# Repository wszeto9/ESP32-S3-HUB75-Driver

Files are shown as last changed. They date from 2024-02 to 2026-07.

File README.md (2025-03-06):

# ESP32-S3-HUB75-Driver

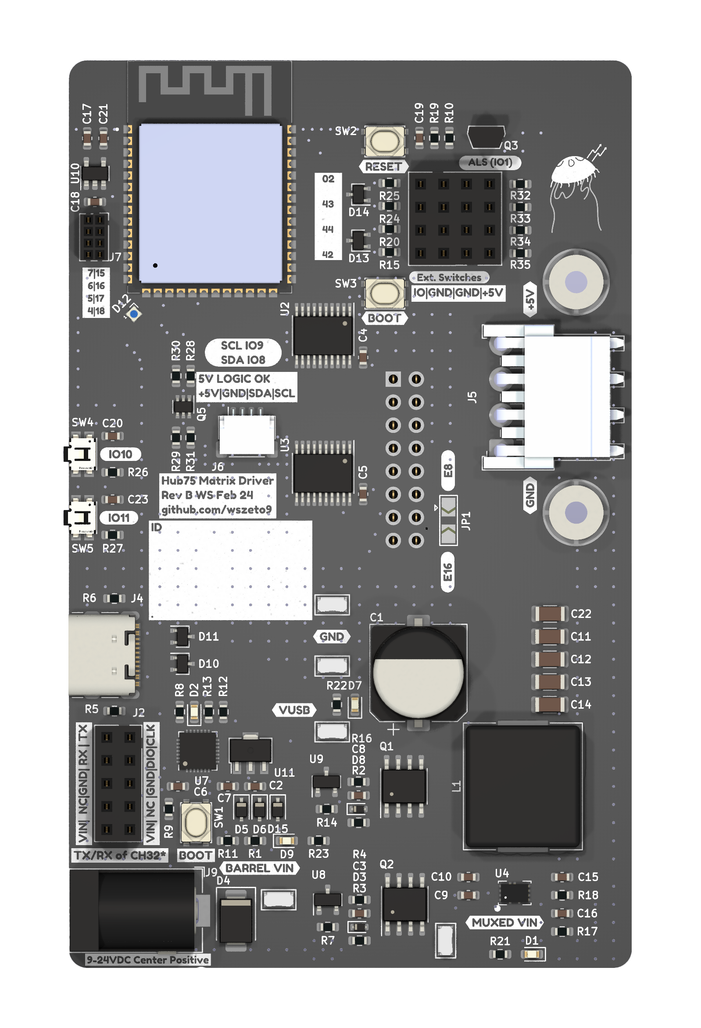
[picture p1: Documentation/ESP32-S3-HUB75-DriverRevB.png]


This board serves as the Matrix Display driver for MIT's 2.007 gameboards in Spring 2024 and Spring 2025. The board can take 4 button inputs, Stemma-QT I2C sensors, and breaks out 8 GPIO pins for future use. The board also features a ambient light sensor to adjust brightness in real time, as well as two buttons to switch modes if needed. The board supports USB-C PD power input up to 20V and USB debugging, as well as a 5.5mm OD / 2.1mm ID barrel jack for 9-24V input. A 5V/6A Buck converter helps ensure that the display is adequately powered. For this reason, it's recommended to power the display off a source higher than 5V for long term purposes. 

The board contains a power mux that automatically switches power sources based on what's present. It will always choose the first power source that's provided. If debugging is desired, it's recommended to first plug in the barrel jack for power, then use the USB port for debugging. This ensures lower power draw from the host computer. 

Upon power up, D7 or D9 will light up based on what power source is present. D2 should blink in accordance to the voltage of the power source (ie 5 blinks is a 5V source). D1 indicates that power is properly being delivered to the converter. 

At this point, the ESP32-S3 should pop up as a virtual COM port over USB. Boot and reset buttons are located by the ESP, but they may not be needed to perform DFU. 

Note: E8 and E16 refer to the pin that is used to act as pin E. This is only present on 64x64 pixel displays and larger. Some displays use pin 8, some displays use pin 16. Adafruit claims they use pin 8 for address E, so use a solder blob to jump the jumper to E8.

Further documentation can be found under the specific firmware builds.

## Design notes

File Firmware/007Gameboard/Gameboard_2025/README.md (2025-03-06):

# 2.007 Spring 2025 Gameboard - Lever Display
This firmware is for the lever displays on the 2.007 Spring 2025 gameboard. The initial codebase is copied from the 2024 Button Displays.

One of the major changes in this firmware compared to most other code one might encounter is that everything is implemented in timer and interrupt peripherals. This means that the flow of the code is quite different from what most people learn when they first start writing code. [Here's a link](https://users.ece.utexas.edu/~valvano/Volume1/E-Book/C12_Interrupts.htm) to learn about interrupts.

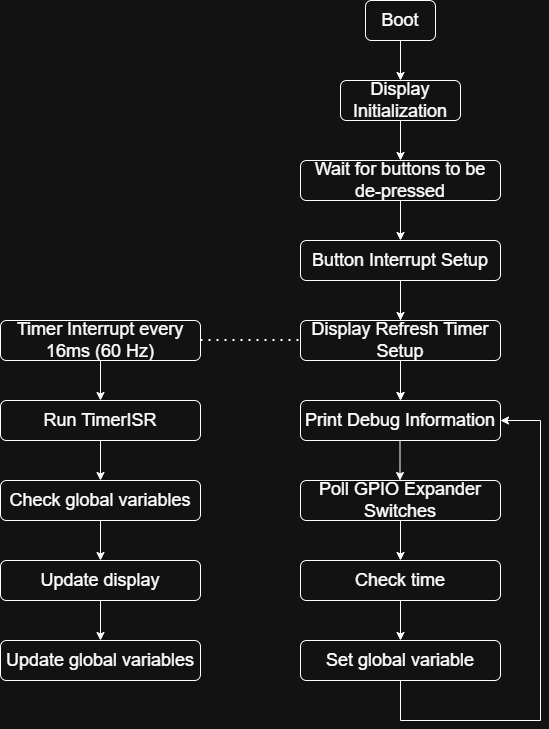
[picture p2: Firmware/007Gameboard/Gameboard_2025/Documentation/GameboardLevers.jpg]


Suggested flowchart for the firmware

The central flow diagram is what is typically taught in code structure. Here, initialization and setup code (usually in `void setup(){}`) is run once and code that repeats is run in a loop (usually in `void loop(){}`). What is special is the two other flow structures on the left and right. They get initialized in setup. 

Timers can trigger interrupts! Timer setups are a lot more hardware-dependent, so refer to the [ESP32 Arduino Framework documentation](https://espressif-docs.readthedocs-hosted.com/projects/arduino-esp32/en/latest/api/timer.html) on how to set up a timer. The timer in this case is set up to interrupt every 16ms, which equiates to about 60 Hz. Once the timer expires, `timerISR` is called, which updates the display. For more specific documentation on all the functions used to draw images to displays, see the dependent [ESP32-HUB75-MatrixPanel-DMA library](https://github.com/mrcodetastic/ESP32-HUB75-MatrixPanel-DMA).

For bitmaps, the `drawXBM565` function is called. This pulls a bitmap array from memory to draw it on the display. There's more documentation on this [here in the examples](https://github.com/mrcodetastic/ESP32-HUB75-MatrixPanel-DMA/tree/master/examples/BitmapIcons). In this firmware, all the image assets are saved in `ImageAssets.h` to clear up space in the main firmware file.

`LEDMatrixConfig.h` is used to define pins for various board revisions. It shouldn't need to be modified unless a new board revision is designed. 

For the 2025 gameboard, since there are 6 levers, it's recommended to poll an [I2C GPIO Expander](https://www.adafruit.com/product/5346) in the main loop. This is to reduce the electrical complexity in doing a board redesign to support 2 additional buttons.

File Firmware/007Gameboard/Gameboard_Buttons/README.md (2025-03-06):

# 2.007 Spring 2024 Gameboard - Button Display

This firmware is for the button displays on the 2.007 Spring 2024 gameboard. 

The device has 4 button inputs that robots can interact with. These buttons must be pressed in a specific sequence to earn points. The button presses are tracked on the display and shown. 

One of the major changes in this firmware compared to most other code one might encounter is that everything is implemented in timer and interrupt peripherals. This means that the flow of the code is quite different from what most people learn when they first start writing code. [Here's a link](https://users.ece.utexas.edu/~valvano/Volume1/E-Book/C12_Interrupts.htm) to learn about interrupts.

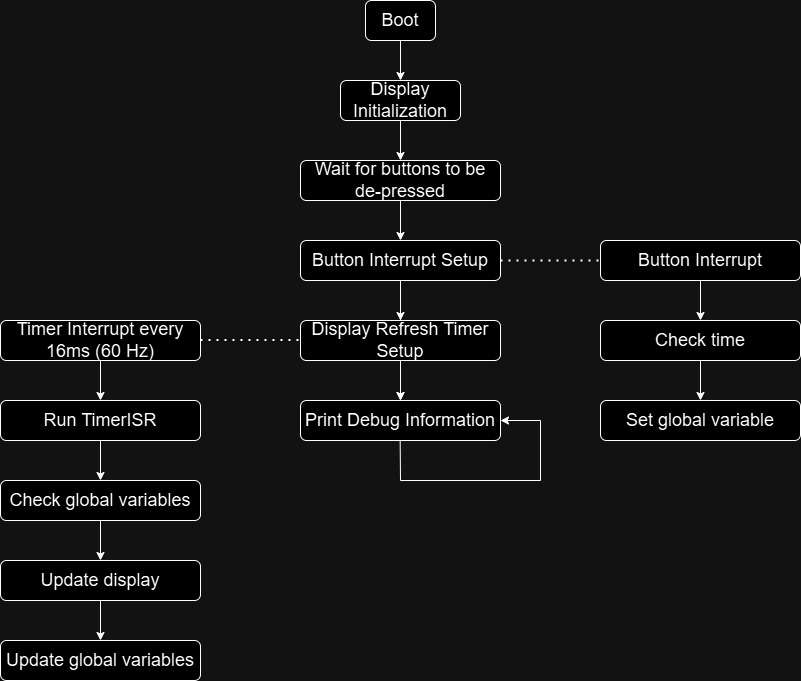
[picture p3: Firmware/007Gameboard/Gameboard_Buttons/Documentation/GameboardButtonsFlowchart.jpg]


Flowchart for the firmware

The central flow diagram is what is typically taught in code structure. Here, initialization and setup code (usually in `void setup(){}`) is run once and code that repeats is run in a loop (usually in `void loop(){}`). What is special is the two other flow structures on the left and right. They get initialized in setup. For the button interrupt, it's initialized as a pin-change interrupt. This means that if the state of the pin changes, a function is called instantaneously without requiring constant polling. It's initialized in this line:

> `attachInterrupt(digitalPinToInterrupt(BUTTON_INPUT_1), ButtonInterruptFunction1, RISING);`

`digitalPinToInterrupt` converts a pin to an interrupt, and `ButtonInterruptFunction1` is the function called when the pin changes, in this case, when the pin rises. The function that's called when an interrupt happens is typically called an Interrupt Service Routine (ISR) since responding to an interrupt is referred to as servicing the interrupt. See [here](https://docs.arduino.cc/language-reference/en/functions/external-interrupts/digitalPinToInterrupt/) for further documentation. 

Four of these interrupts are set up to account for the four buttons that are connected. They set a global variable to the time that the button is pressed. It's good practice to make the ISR is as short as possible since it brings the microcontroller away from the main loop. Specifically, millis() is on a 1 millisecond timer interrupt to update the runtime. Arduino tends to get very unhappy and crashes when another ISR takes long enough to block millis() from running. For this reason, it's advisible that interrupts only set variables and not include waits. `Serial.print` functions typically also take too long that it's not recommended to use them in ISRs.

Timers can also trigger interrupts! Timer setups are a lot more hardware-dependent, so refer to the [ESP32 Arduino Framework documentation](https://espressif-docs.readthedocs-hosted.com/projects/arduino-esp32/en/latest/api/timer.html) on how to set up a timer. The timer in this case is set up to interrupt every 16ms, which equiates to about 60 Hz. Once the timer expires, `timerISR` is called, which updates the display. For more specific documentation on all the functions used to draw images to displays, see the dependent [ESP32-HUB75-MatrixPanel-DMA library](https://github.com/mrcodetastic/ESP32-HUB75-MatrixPanel-DMA).

For bitmaps, the `drawXBM565` function is called. This pulls a bitmap array from memory to draw it on the display. There's more documentation on this [here in the examples](https://github.com/mrcodetastic/ESP32-HUB75-MatrixPanel-DMA/tree/master/examples/BitmapIcons). In this firmware, all the image assets are saved in `ImageAssets.h` to clear up space in the main firmware file.

`LEDMatrixConfig.h` is used to define pins for various board revisions. It shouldn't need to be modified unless a new board revision is designed.

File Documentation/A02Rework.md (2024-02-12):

# A02 Rework guide

There's too many mistakes. Here's a summary of all the edits that need to be made. 

## Bulk Capacitance on Vin

Yep. Forgot bulk capacitance. Scrape off solder mask and add a 220uF/35V capacitor to Vin_Muxed to GND. Vin_Muxed is marked in yellow, and GND is marked in GND for reference. The suggested place to scrape off solder mask is marked in red.  

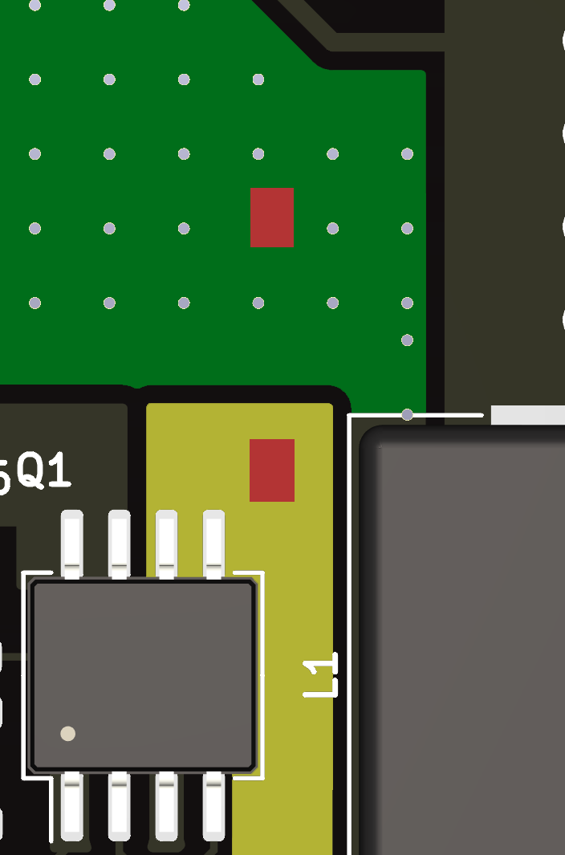
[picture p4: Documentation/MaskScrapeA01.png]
 

A01 PCB and edits to be made to add bulk capacitance

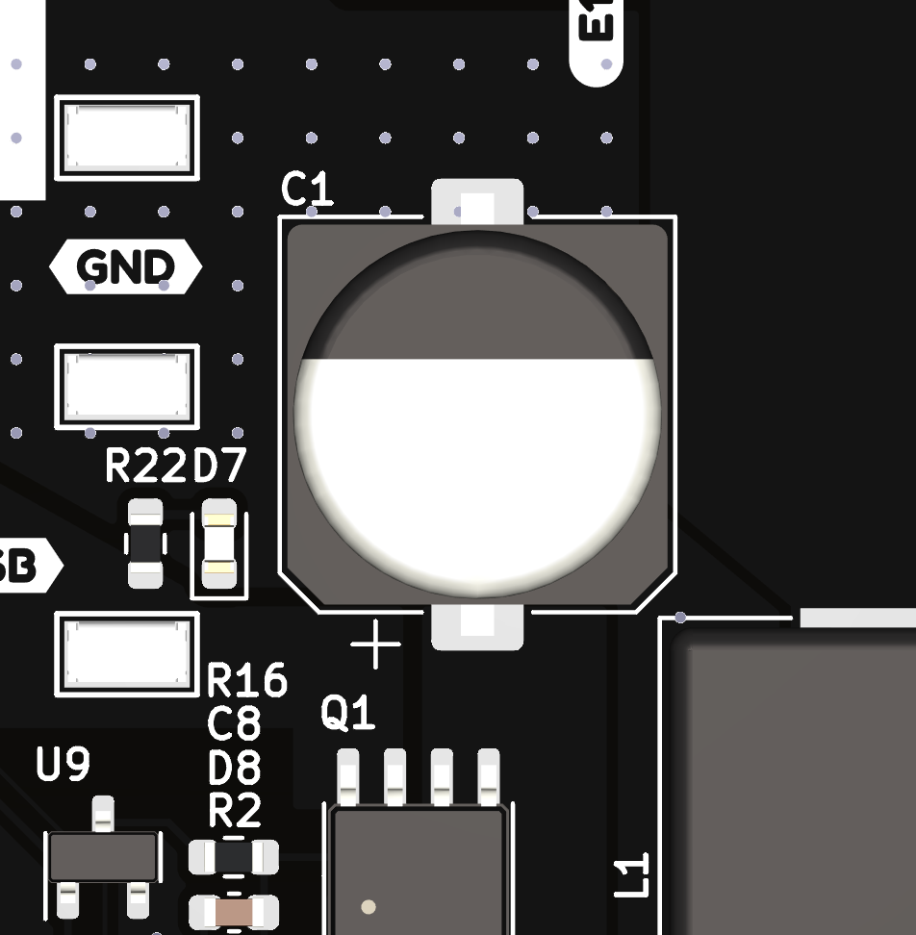
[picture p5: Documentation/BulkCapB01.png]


B01 PCB has bulk capacitor without need for edits

## High-Side Switch Slew-Rate limiting

In A01, some chargers would not deliver 20V when requested. This is because when the bulk capacitance was added, the inrush current would be too high. See the ~ 25A inrush when the high-side switch is turned on. The solution is modify C8 to be a [1uF Capacitor](https://product.samsungsem.com/mlcc/CL10A105KB8NNN.do). It is suggested to use a capacitor with a de-rated capacitance of 200nF at 15V DC Bias. C3 is also edited to have the same slew rate with the barrel jack power. 

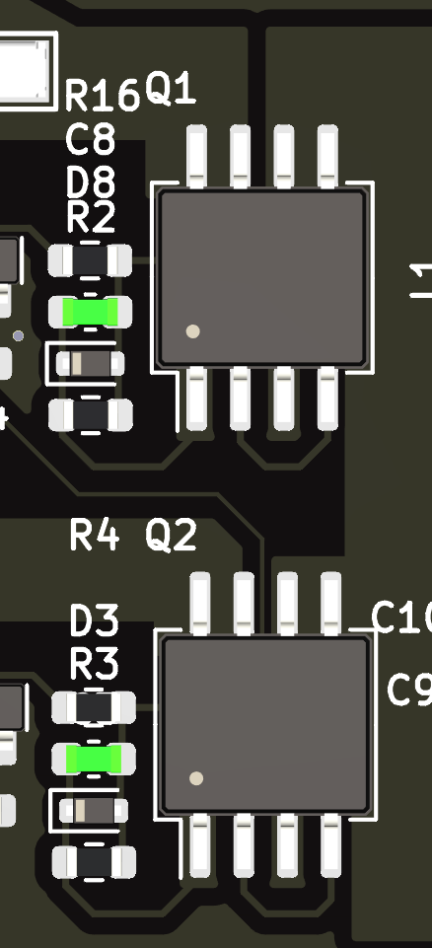
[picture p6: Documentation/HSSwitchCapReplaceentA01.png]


C8 and C3 are highlighted to be edited to be a 1uF capacitor. 

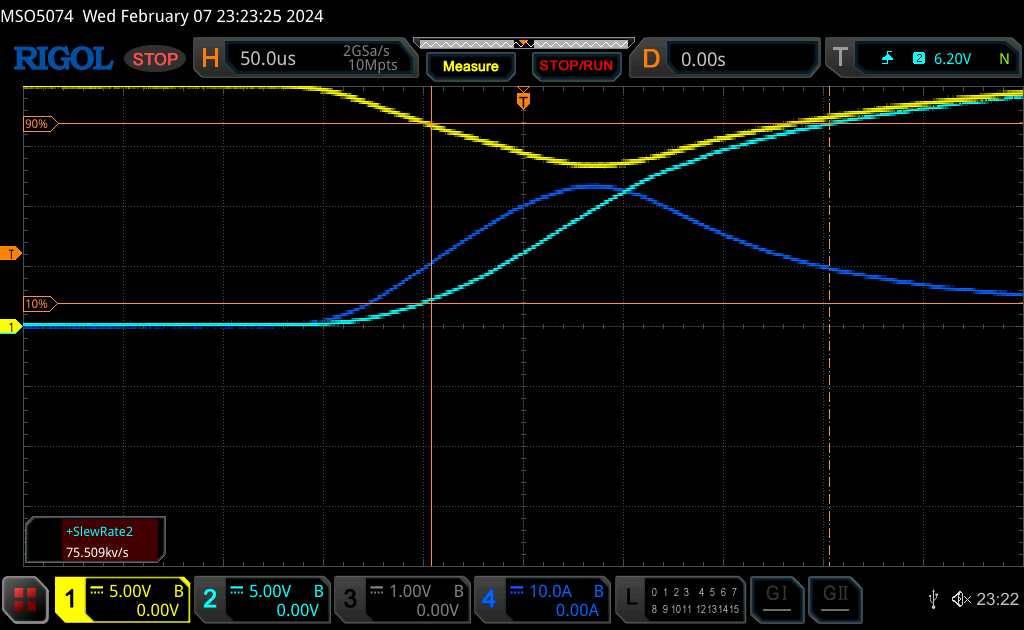
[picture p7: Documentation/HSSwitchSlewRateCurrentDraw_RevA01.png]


A01 High-Side Switch turn-on transient. The large capacitance and fast turn-on causes a 25A inrush current and a significant voltage sag. 

- Yellow[1]: Vin_USB_C (V)
- Light Blue[2]: Vout_Muxed (V)
- Dark Blue[4]: Current In (A)

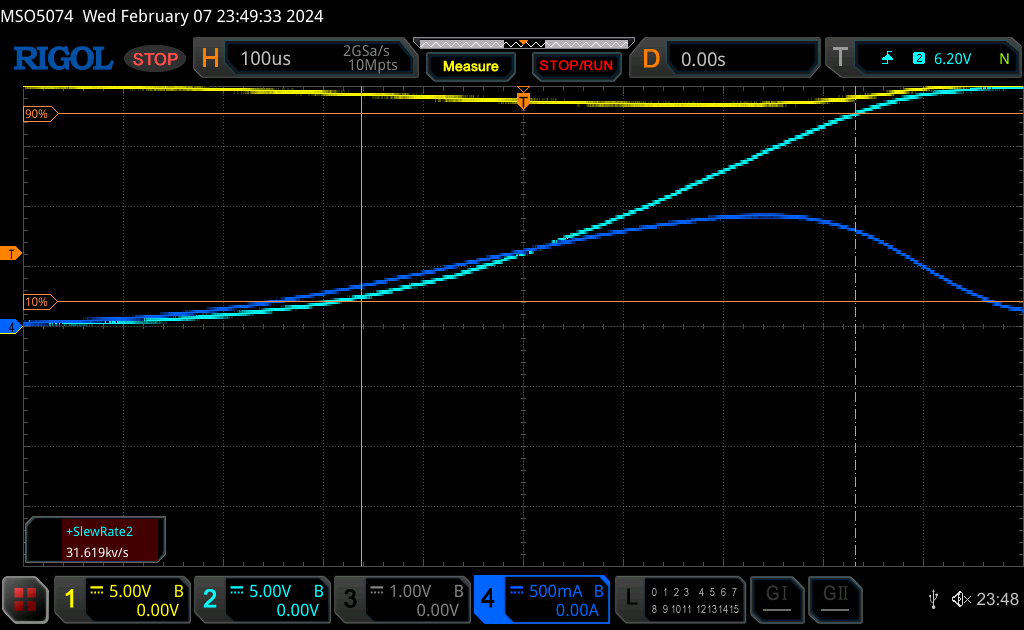
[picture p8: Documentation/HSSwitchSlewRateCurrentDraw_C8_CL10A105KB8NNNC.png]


A02 High-Side Switch turn-on transient.  The larger capacitor on  the FET gates causes a slower slew rate, reducing the inrush current to be under 1A. 

- Yellow[1]: Vin_USB_C (V)
- Light Blue[2]: Vout_Muxed (V)
- Dark Blue[4]: Current In (A)

## CH32X035 LED Indicator Brightness

The LED is a bit bright. Edit R10 (highlighted below) to around 5K. 

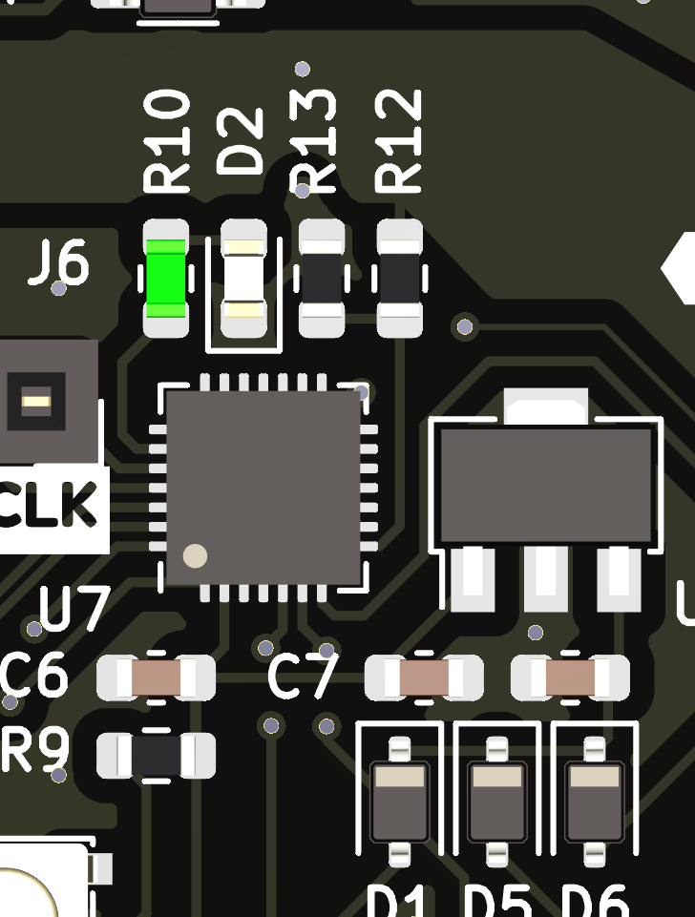
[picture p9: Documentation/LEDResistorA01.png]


## CH32X035 Voltage Sense 

The CH32X035 Arduino Library has no floating point divide instructions. The "solution" is to replace the low-side resistor (R13, R11) to be 3.3K and the high-side resistor (R12, R1) to be 18K. This ratio allows for `uint8_t Voltage = analogRead(VSensePin) >> 7` to be representative of the voltage being measured (within 1V or so), while not needing floating point division. 

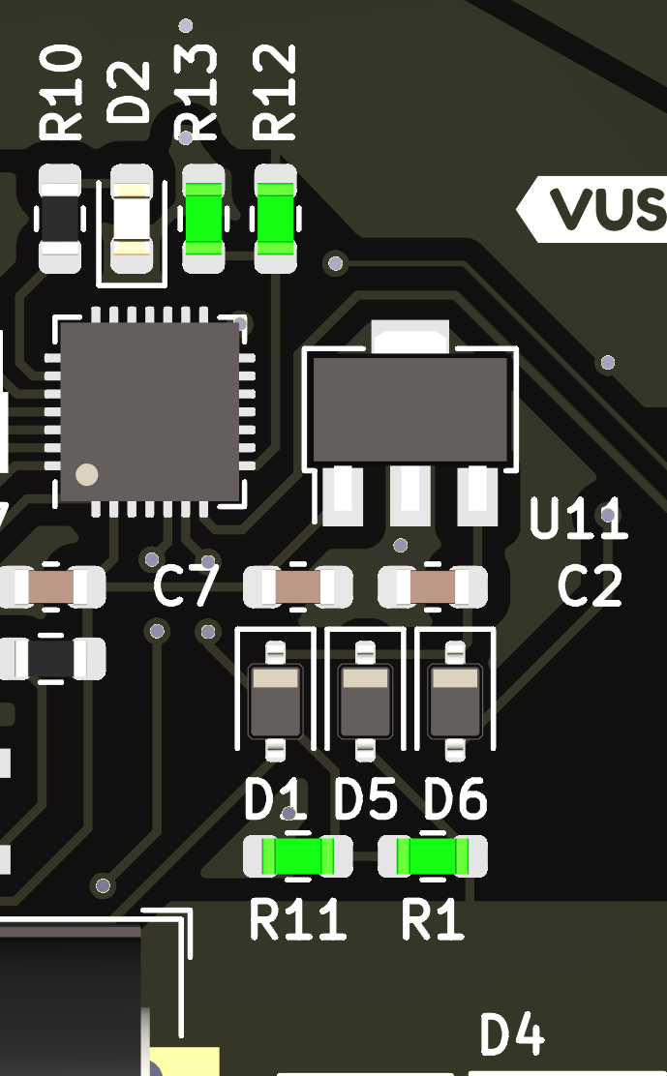
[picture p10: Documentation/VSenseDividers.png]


## ESD Protection

The ESD protection diode has a clamp voltage of 5V. Since USB-C PD can go up to 20V, this may damage the ESD diode. To fix this, the VCC pin of the ESD diode must be disconnected from the VBUS of the USB port. Lift the red colored pin from the pad to disconnect it. 

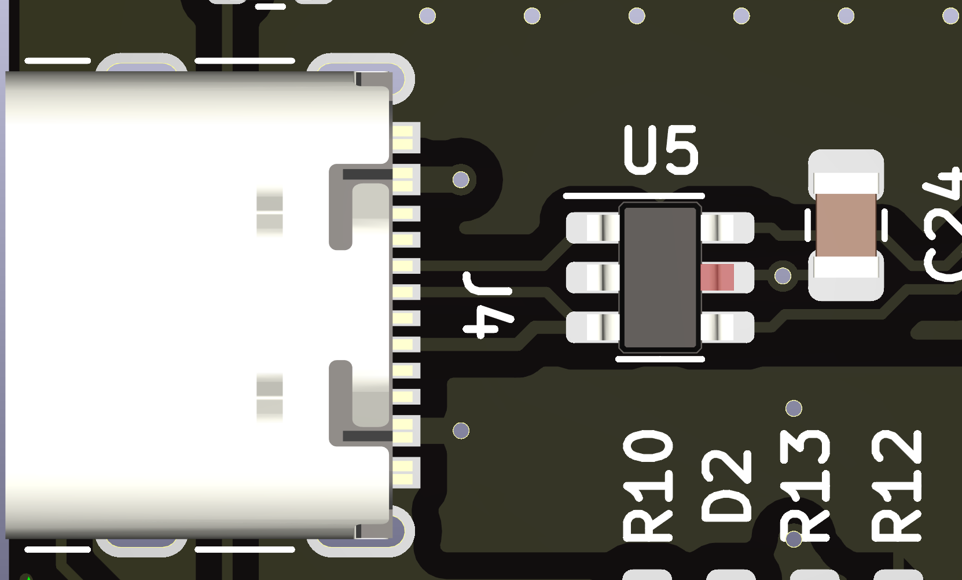
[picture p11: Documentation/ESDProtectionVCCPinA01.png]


## Logic Level Shifter pinout

The pinout is not right. Maybe 3AM layout will do that. On U3, mask off pin 3 so it's not connected to GND. This may be done with a small piece of kapton tape, liquid curable solder mask, or by lifting the pin high above the PCB. 

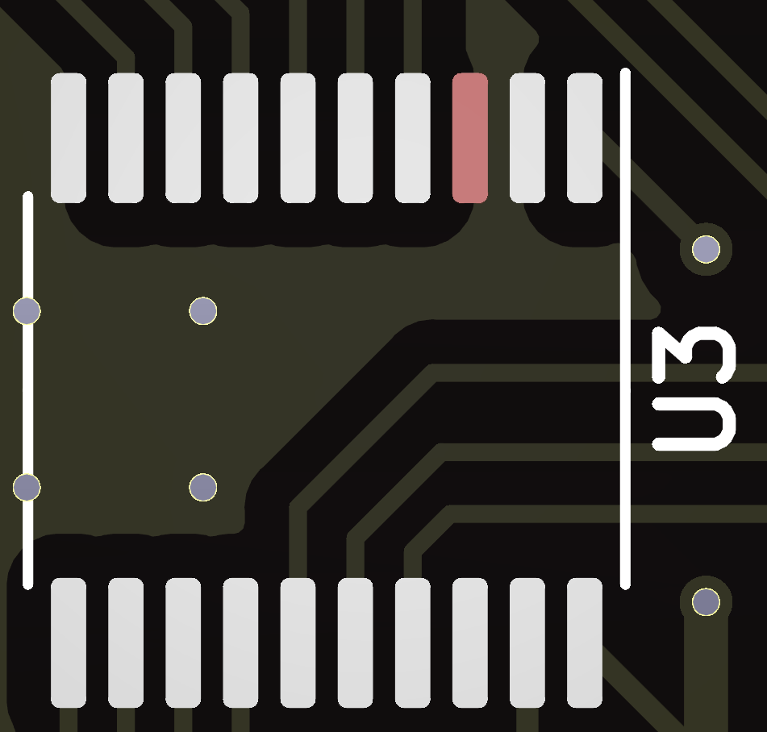
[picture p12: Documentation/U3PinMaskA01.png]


Next, jump that pin to IO12 of the ESP32-S3, shown below. 

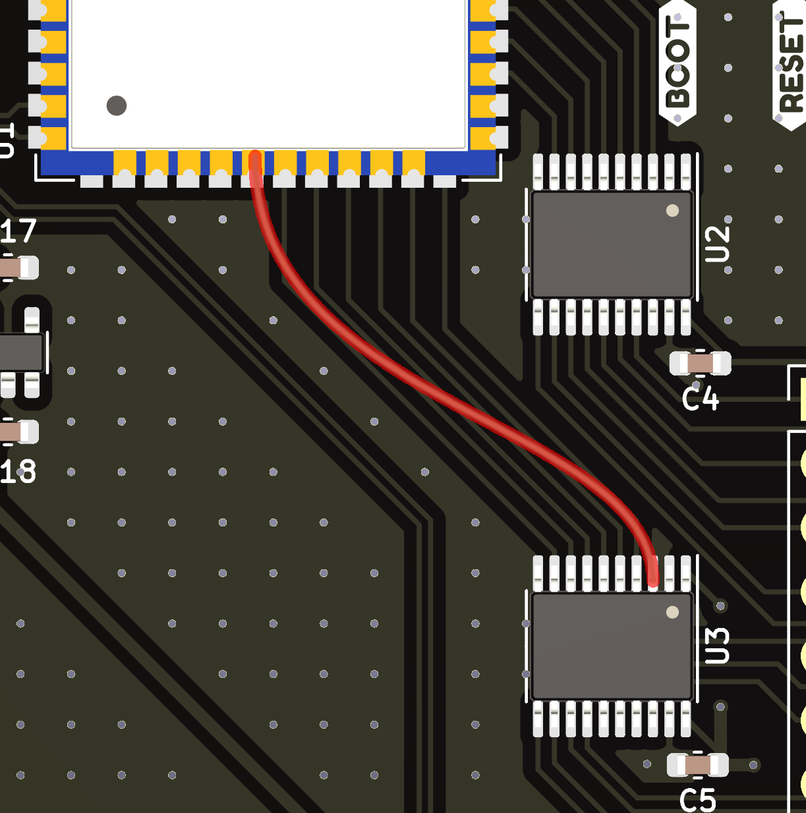
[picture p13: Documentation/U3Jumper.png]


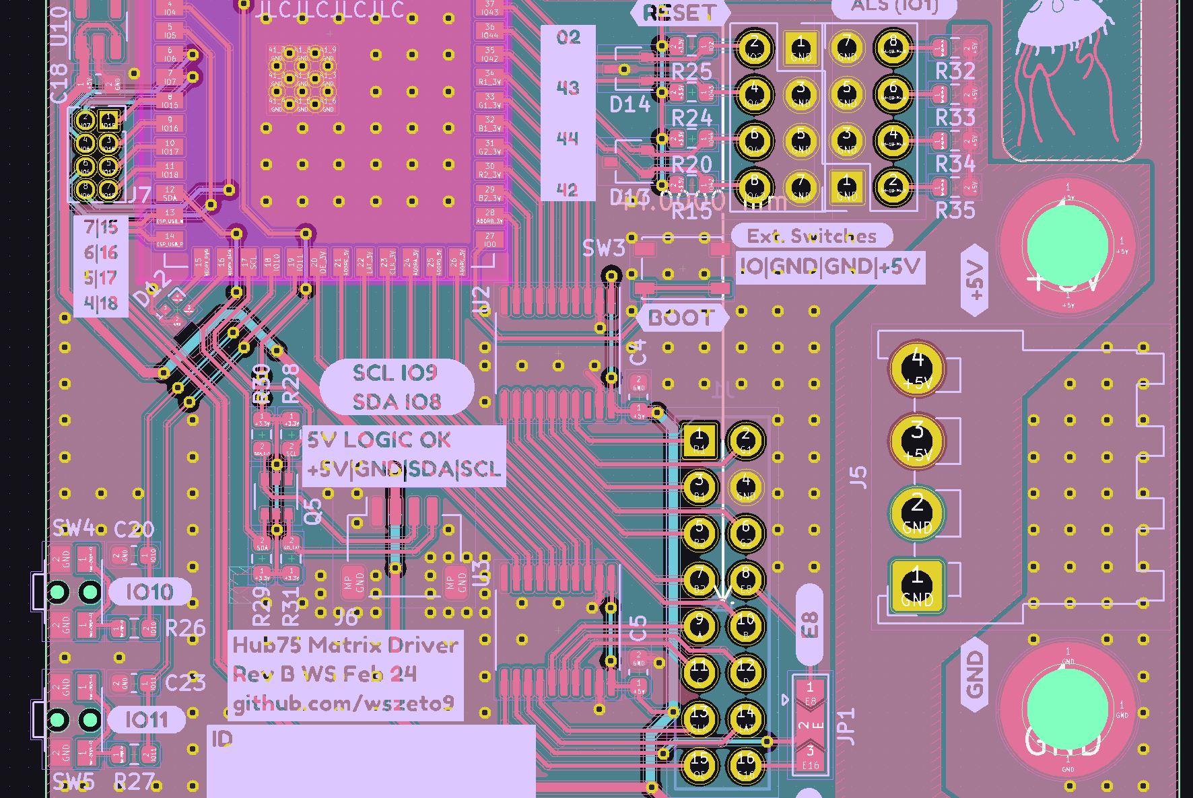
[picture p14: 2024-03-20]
Rev A Auxillary Board/RevBMainBoard.png

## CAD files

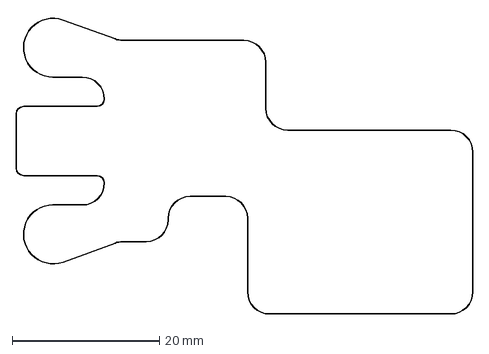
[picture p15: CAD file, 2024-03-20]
Rev A Auxillary Board/BoardOutline.dxf
62.1 x 40.5 mm

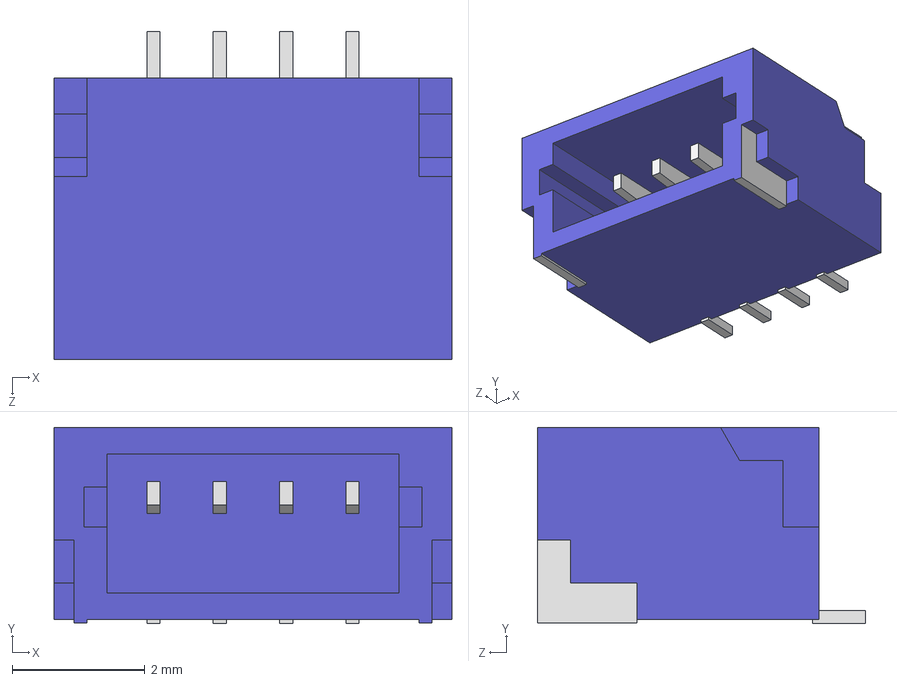
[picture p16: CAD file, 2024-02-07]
Rev B/SM04B-SRSS-TB.STEP
6.00 x 2.96 x 4.95 mm

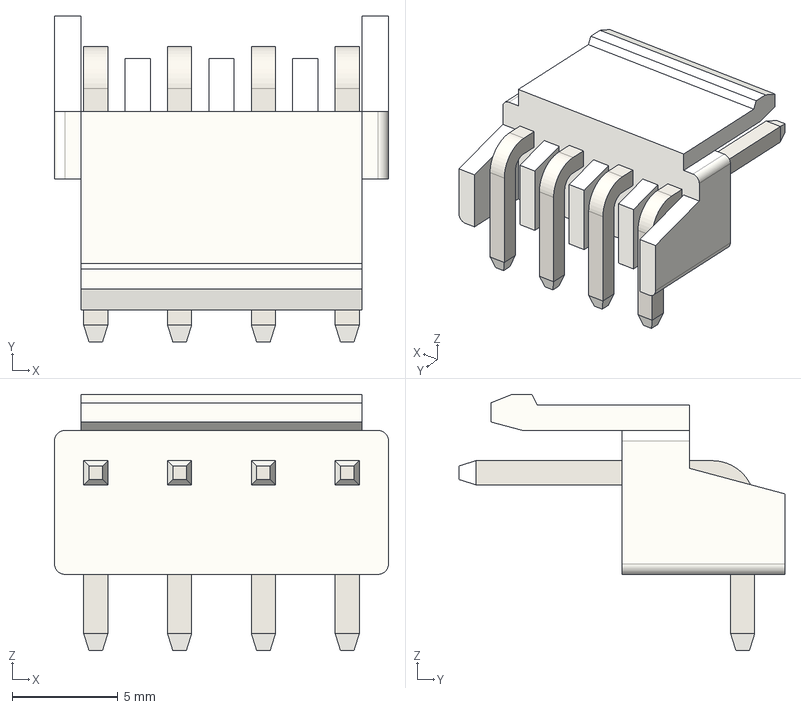
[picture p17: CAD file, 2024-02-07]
Rev B/JST_VH_S4P-VH_1x04_P3.96mm_Horizontal.STEP
15.8 x 15.4 x 12.1 mm

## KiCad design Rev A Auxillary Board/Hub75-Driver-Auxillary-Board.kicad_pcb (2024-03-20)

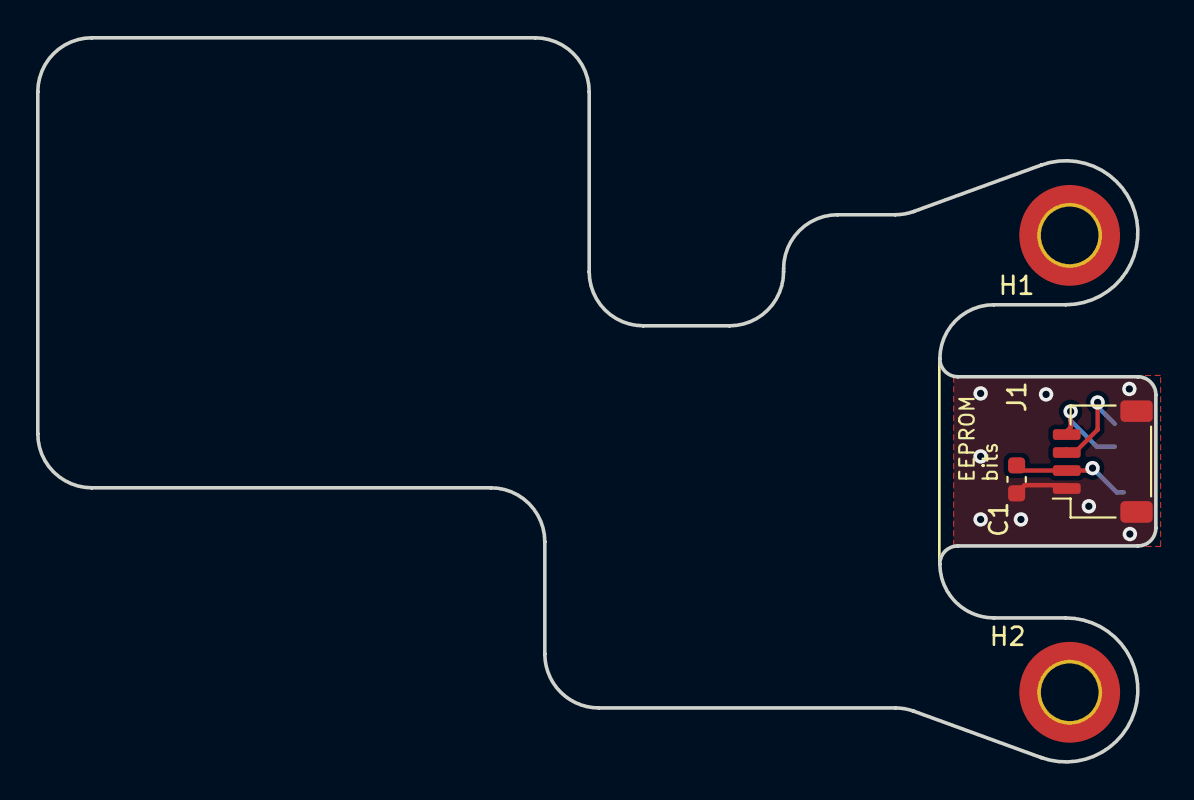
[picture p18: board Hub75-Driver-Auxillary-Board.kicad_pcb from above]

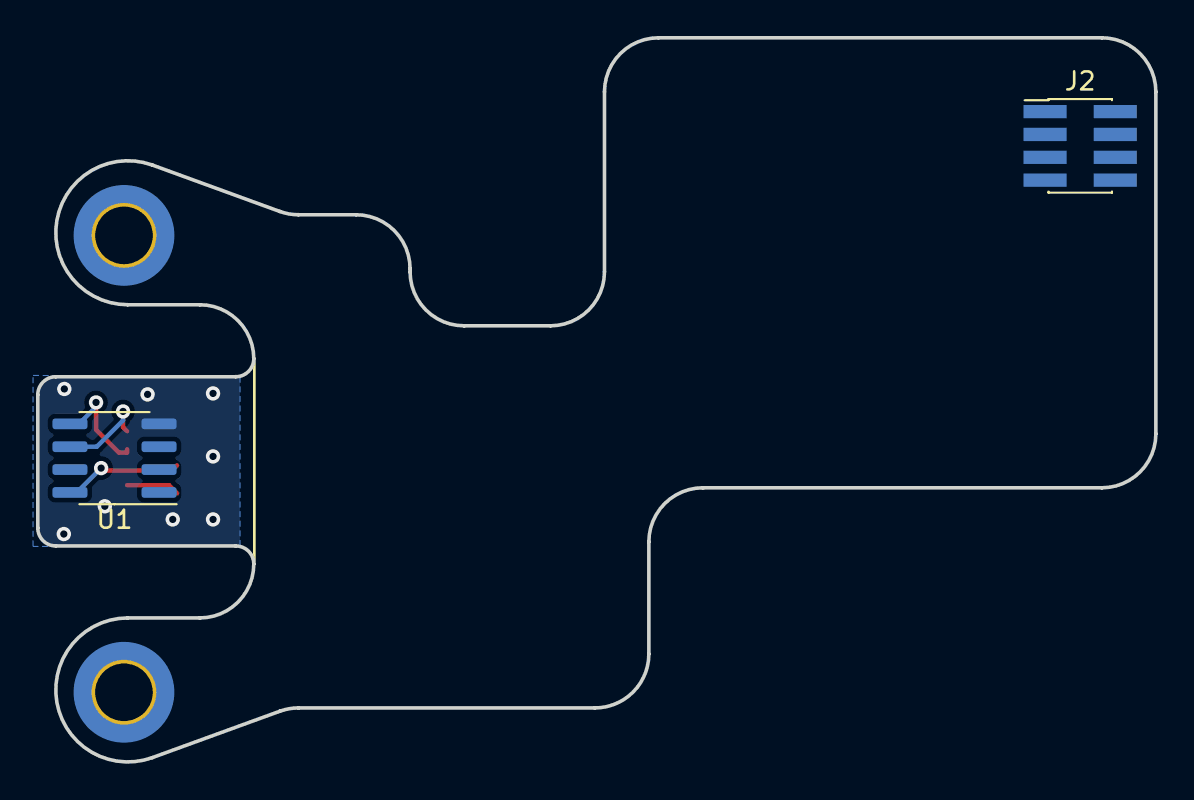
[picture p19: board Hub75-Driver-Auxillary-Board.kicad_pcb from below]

Board: 2 copper layers, 62.1 x 40.2 mm, 6 parts (2 on the bottom side), 4 nets.

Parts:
C1: 0603,100nF,50V,X7R; C_0603_1608Metric
H1, H2: MountingHole_Pad; MountingHole_3.2mm_M3_DIN965_Pad_TopBottom
J1: JST-SH-SM04B; JST_SH_SM04B-SRSS-TB_1x04-1MP_P1.00mm_Horizontal
J2: Conn_02x04_Odd_Even; PinHeader_2x04_P1.27mm_Vertical_SMD
U1: M24C01-FMN; SOIC-8_3.9x4.9mm_P1.27mm

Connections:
+5VD: C1.1, J1.2, U1.8 (VCC)
/SCL: J1.4, U1.6 (SCL)
/SDA: J1.3, U1.5 (SDA)
GNDS: C1.2, J1.1, J1.MP (MountPin), U1.4 (VSS)

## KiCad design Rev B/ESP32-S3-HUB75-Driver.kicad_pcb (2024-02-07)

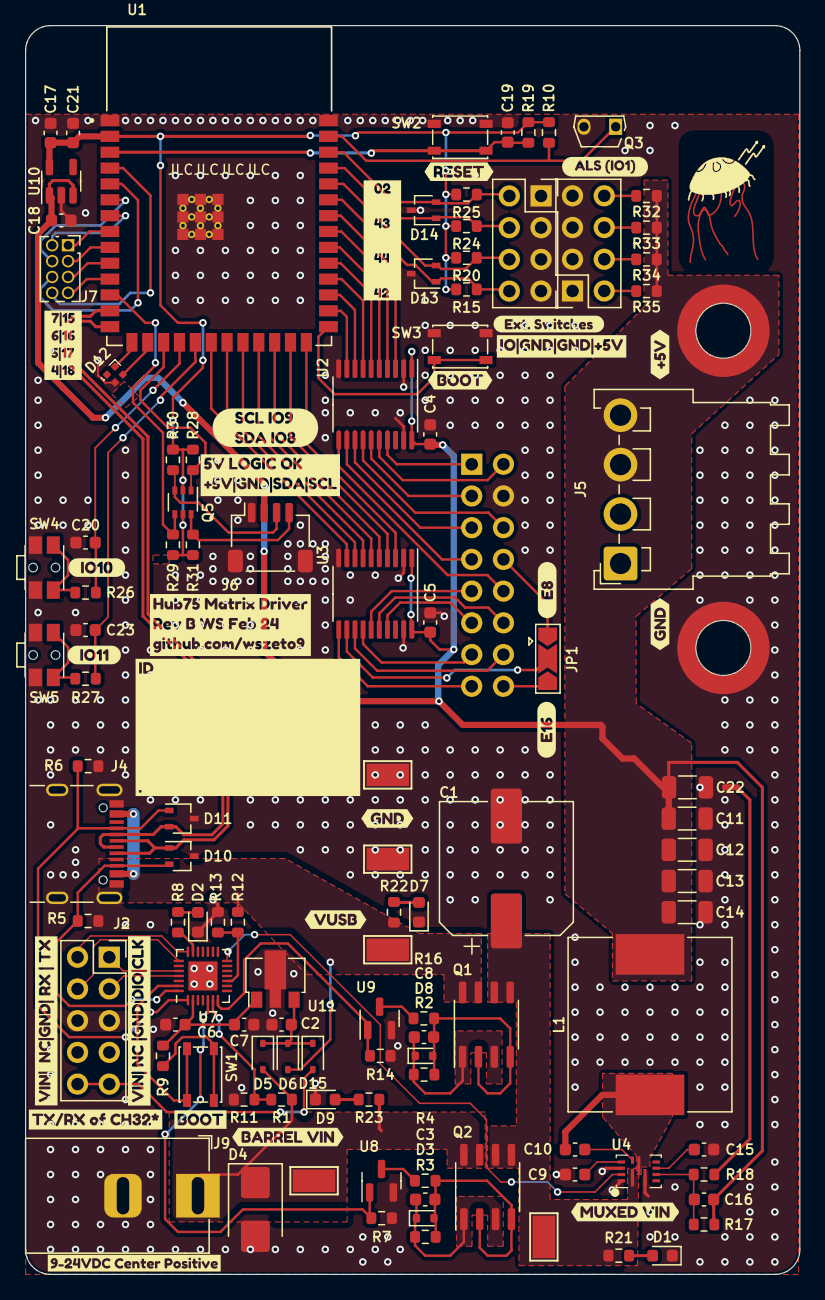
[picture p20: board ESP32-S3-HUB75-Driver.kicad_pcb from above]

Board: 2 copper layers, 62.0 x 100.0 mm, 137 parts (1 on the bottom side), 100 nets.

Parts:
C1: 560uF/25V; CP_Elec_10x12.5
C2, C9, C19: 0603,1uF,50V,X5R; C_0603_1608Metric
C3, C4, C5, C6, C7, C8, C10, C15, C20, C21, C23: 0603,100nF,50V,X7R; C_0603_1608Metric
C11, C12, C13, C14, C22: 1206,22uF,25V,X5R; C_1206_3216Metric
C16: 0603,22pF,50V,C0G; C_0603_1608Metric
C17, C18: 0603,10uF,10V,X5R; C_0603_1608Metric
D1, D2, D7, D9: LED_White; LED_0603_1608Metric
D3, D8: BZT52C15T-7; D_SOD-523
D4: SMBJ24A; D_SMB
D5, D6, D15: 1N4148WS; D_SOD-323
D10, D11, D13, D14: SP0502BAJT; SOT-323_SC-70
D12: SK6805-EC15; LED_SK6812_EC15_1.5x1.5mm
H1, H2: WA-SMSI M3-H5mm; Mounting_Wuerth_WA-SMSI-M3_H5mm_9774050360
J1: 2x08 Pin Socket P2.54mm; PinSocket_2x08_P2.54mm_Vertical
J2: Conn_02x05_Odd_Even; PinSocket_2x05_P2.54mm_Vertical
J3, J8: 2x04 Socket P2.54mm; PinSocket_2x04_P2.54mm_Vertical
J4: USB4105; USB_C_Receptacle_GCT_USB4105-xx-A_16P_TopMnt_Horizontal
J5: S4P-VH; JST_VH_S4P-VH_1x04_P3.96mm_Horizontal
J6: JST-SH-SM04B; JST_SH_SM04B-SRSS-TB_1x04-1MP_P1.00mm_Horizontal
J7: 2x04 Socket P1.27mm; PinSocket_2x04_P1.27mm_Vertical
J9: Barrel_Jack; BarrelJack_Horizontal
JP1: EJumper; SolderJumper-3_P2.0mm_Open_TrianglePad1.0x1.5mm
L1: DR125-1R0-R; L_Sunlord_MWSA1206S-1R5
LOGO1: Logo
NT1: NetTie_2; NetTie-2_SMD_Pad0.5mm
Q1, Q2: DMP3036SSD; SO-8_3.9x4.9mm_P1.27mm
Q3: Q_Photo_NPN; TO-92S-2
Q5: BSS138BKS; SOT-363_SC-70-6
R1, R4, R12, R16, R19, R28, R29, R30, R31: 0603,10k; R_0603_1608Metric
R2, R3: 0603,100k; R_0603_1608Metric
R5, R6: 0603,5.1k; R_0603_1608Metric
R7, R8, R10, R11, R13, R14, R15, R20, R21, R22, R23, R24, R25: 0603,1k; R_0603_1608Metric
R9: 0603,4.7k; R_0603_1608Metric
R17, R26, R27: 0603,49.9k; R_0603_1608Metric
R18: 0603,6.8k; R_0603_1608Metric
R32, R33, R34, R35: 0603,0; R_0603_1608Metric
SW1, SW2, SW3: PTS810 SJM; SW_SPST_PTS810
SW4, SW5: EVQ-P7C01P; SW_SPST_EVQP7C
TP1, TP2, TP3, TP4, TP5: TestPoint; TestPoint_Keystone_5015_Micro-Minature
U1: ESP32-S3-WROOM-1-N16; XCVR_ESP32-S3-WROOM-1-N16R2
U2, U3: 74AHCT245PW,118; TSSOP-20_4.4x6.5mm_P0.65mm
U4: TPS51385RJNR; VQFN-HR12_RJN_TEX
U7: CH32X035G8U6; QFN-28-1EP_4x4mm_P0.4mm_EP2.3x2.3mm
U8, U9: AO3400A; SOT-23
U10: AP2112K-3.3; SOT-23-5
U11: L78L05_SOT89; SOT-89-3
kibuzzard-65AE10D9: G***; kibuzzard-65AE10D9
kibuzzard-65AE10E5: G***; kibuzzard-65AE10E5
kibuzzard-65AE16BC: G***; kibuzzard-65AE16BC
kibuzzard-65AE16C6: G***; kibuzzard-65AE16C6
kibuzzard-65AE17F6: G***; kibuzzard-65AE17F6
kibuzzard-65AE1571: G***; kibuzzard-65AE1571
kibuzzard-65AE1583: G***; kibuzzard-65AE1583
kibuzzard-65AE1804: G***; kibuzzard-65AE1804
kibuzzard-65BF1DC3: G***; kibuzzard-65BF1DC3
kibuzzard-65BF1E36: G***; kibuzzard-65BF1E36
kibuzzard-65BFF68F: G***; kibuzzard-65BFF68F
kibuzzard-65C14F52: G***; kibuzzard-65C14F52
kibuzzard-65C018C7: G***; kibuzzard-65C018C7
kibuzzard-65C018EB: G***; kibuzzard-65C018EB
kibuzzard-65C019AC: G***; kibuzzard-65C019AC
kibuzzard-65C027AA: G***; kibuzzard-65C027AA
kibuzzard-65C027DC: G***; kibuzzard-65C027DC
kibuzzard-65C028A7: G***; kibuzzard-65C028A7
kibuzzard-65C028B8: G***; kibuzzard-65C028B8
kibuzzard-65C150B0: G***; kibuzzard-65C150B0
kibuzzard-65C150D7: G***; kibuzzard-65C150D7
kibuzzard-65C1584F: G***; kibuzzard-65C1584F
kibuzzard-65C01916: G***; kibuzzard-65C01916
kibuzzard-65C01956: G***; kibuzzard-65C01956
kibuzzard-65C06362: G***; kibuzzard-65C06362
kibuzzard-65C15813: G***; kibuzzard-65C15813

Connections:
+3.3V: C17.1, C21.1, Q5.2 (G), Q5.5 (G), R10.1, R15.2, R19.1, R20.2, R24.2, R25.2, R28.1, R29.1, R30.1, R31.1, U1.2 (3V3), U10.5 (VOUT)
+5V: C4.1, C5.1, C11.1, C12.1, C13.1, C14.1, C16.1, C18.1, C22.1, H1.1, J5.3, J5.4, J6.2, L1.2, R17.1, R32.2, R33.2, R34.2, R35.2, U2.1 (DIR), U2.20 (VCC), U3.1 (DIR), U3.20 (VCC), U10.1 (VIN), U10.3 (EN)
/5V6A Buck/BuckEna: U4.11 (EN), U7.14 (PB3)
/A: J1.9, U3.15 (B3)
/ADDRA_3V: U1.24 (IO47), U3.5 (A3)
/ADDRB_3V: U1.28 (IO35), U2.9 (A7)
/ADDRC_3V: U1.26 (IO45), U3.3 (A1)
/ADDRD_3V: U1.25 (IO48), U3.4 (A2)
/ADDRE_3V: U1.21 (IO13/SDI), U3.8 (A6)
/B: J1.10, U2.11 (B7)
/B1: J1.3, U2.15 (B3)
/B1_3V: U1.32 (IO39), U2.5 (A3)
/B2: J1.7, U2.12 (B6)
/B2_3V: U1.29 (IO36), U2.8 (A6)
/C: J1.11, U3.17 (B1)
/CLK: J1.13, U3.14 (B4)
/CLK_3V: U1.23 (IO21), U3.6 (A4)
/D: J1.12, U3.16 (B2)
/E: JP1.2 (C), U3.12 (B6)
/E8: J1.8, JP1.1 (A)
/E16: J1.16, JP1.3 (B)
/ESP_USB_N: D11.2 (K), J4.A7 (D-), J4.B7 (D-), U1.13 (IO19)
/ESP_USB_P: D10.1 (K), J4.A6 (D+), J4.B6 (D+), U1.14 (IO20)
/G1: J1.2, U2.16 (B2)
/G1_3V: U1.33 (IO40), U2.4 (A2)
/G2: J1.6, U2.14 (B4)
/G2_3V: U1.31 (IO38), U2.6 (A4)
/IO0: SW3.2 (B), U1.27 (IO0)
/IO1: Q3.1 (C), R10.2, U1.39 (IO1)
/IO2: D14.2 (K), J8.2, R25.1, U1.38 (IO2)
/IO4: J7.8, U1.4 (IO4)
/IO5: J7.6, U1.5 (IO5)
/IO6: J7.4, U1.6 (IO6)
/IO7: J7.2, U1.7 (IO7)
/IO10: C20.1, R26.2, U1.18 (IO10/CS)
/IO11: C23.1, R27.2, U1.19 (IO11/SDO)
/IO15: J7.1, U1.8 (IO15)
/IO16: J7.3, U1.9 (IO16)
/IO17: J7.5, U1.10 (IO17)
/IO18: J7.7, U1.11 (IO18)
/IO42: D13.1 (K), J8.8, R15.1, U1.35 (IO42)
/IO43: D14.1 (K), J8.4, R24.1, U1.37 (TXD0)
/IO44: D13.2 (K), J8.6, R20.1, U1.36 (RXD0)
/LAT: J1.14, U3.13 (B5)
/LAT_3V: U1.22 (IO14), U3.7 (A5)
/NEOPX_DATA: D12.3 (DIN), U1.16 (IO46)
/NEOPX_PWR: D12.4 (VDD), U1.15 (IO3)
/OE: J1.15, U3.11 (B7)
/OE_3V: U1.20 (IO12/CLK), U3.9 (A7)
/Power and USB Inputs/5V_PROG: D15.2 (A), J2.9, J2.10
/Power and USB Inputs/CC1: D11.1 (K), J4.A5 (CC1), R6.2, U7.1 (PC15/CC2)
/Power and USB Inputs/CC2: D10.2 (K), J4.B5 (CC2), R5.2, U7.28 (PC14/CC1)
/Power and USB Inputs/CH32_RX: J2.4, U7.22 (PB11)
/Power and USB Inputs/CH32_TX: J2.2, U7.21 (PB10)
/Power and USB Inputs/CommonSourceBarrel: C3.1, D3.1 (K), Q2.1 (S), Q2.3 (S), R3.1
/Power and USB Inputs/CommonSource_USBCPower: C8.1, D8.1 (K), Q1.1 (S), Q1.3 (S), R2.1
/Power and USB Inputs/ENA_BARREL: R7.1, U7.5 (PA0), U8.1 (G)
/Power and USB Inputs/ENA_USBPD: R14.1, U7.7 (PA2), U9.1 (G)
/Power and USB Inputs/Gate_Barrel: C3.2, D3.2 (A), Q2.2 (G), Q2.4 (G), R3.2, R4.1
/Power and USB Inputs/Gate_USBCPower: C8.2, D8.2 (A), Q1.2 (G), Q1.4 (G), R2.2, R16.1
/Power and USB Inputs/SWDCLK: J2.1, U7.24 (PC19/DCK)
/Power and USB Inputs/SWDIO: J2.3, U7.25 (PC18/DIO)
/Power and USB Inputs/USB_CH32_P: SW1.1 (A), U7.27 (PC17/UDP)
/Power and USB Inputs/VCC_CH32: C6.1, C7.1, R9.1, U7.2 (VDD), U11.1 (OUT)
/Power and USB Inputs/VIN_BARREL: D4.1 (K), D5.2 (A), J9.1, Q2.7 (D), Q2.8 (G), R1.1, R23.1, TP3.1
/Power and USB Inputs/VSENSE_BARREL: R1.2, R11.1, U7.6 (PA1)
/Power and USB Inputs/VSENSE_USBPD: R12.2, R13.1, U7.10 (PA5)
/Power and USB Inputs/VUSBC: D6.2 (A), J4.A4 (VBUS), J4.A9 (VBUS), J4.B4 (VBUS), J4.B9 (VBUS), Q1.7 (D), Q1.8 (G), R12.1, R22.1, TP2.1
/R1: J1.1, U2.17 (B1)
/R1_3V: U1.34 (IO41), U2.3 (A1)
/R2: J1.5, U2.13 (B5)
/R2_3V: U1.30 (IO37), U2.7 (A5)
/SCL: Q5.1 (S), R28.2, U1.17 (IO9/SCL)
/SCL_EXT: J6.4, Q5.6 (D), R31.2
/SDA: Q5.4 (S), R29.2, U1.12 (IO8/SDA)
/SDA_EXT: J6.3, Q5.3 (D), R30.2
/VIN_MUXED: C1.1, Q1.5 (D), Q1.6 (G), Q2.5 (D), Q2.6 (G), R21.1, TP1.1, U4.1 (VIN)
/~RST: C19.1, R19.2, SW2.2 (B), U1.3 (EN)
GND: C1.2, C2.2, C4.2, C5.2, C6.2, C7.2, C9.2, C11.2, C12.2, C13.2, C14.2, C15.2, C17.2, C18.2, C19.2, C20.2, C21.2, C22.2, C23.2, D1.1 (K), D2.1 (K), D4.2 (A), D7.1 (K), D9.1 (K), D10.3 (A), D11.3 (A), D12.2 (VSS), D13.3 (A), D14.3 (A), H2.1, J1.4, J2.5, J2.6, J3.1, J3.3, J3.5, J3.7, J4.A1 (GND), J4.A12 (GND), J4.B1 (GND), J4.B12 (GND), J4.S1 (SHIELD), J5.1, J5.2, J6.1, J6.MP (MountPin), J8.1, J8.3, J8.5, J8.7, J9.2, NT1.1, Q3.2 (E), R5.1, R6.1, R7.2, R11.2, R13.2, R14.2, SW2.1 (A), SW3.1 (A), SW4.2 (B), SW5.2 (B), TP4.1, TP5.1, U1.1 (GND), U1.40 (GND), U1.41_1 (GND), U1.41_2 (GND), U1.41_3 (GND), U1.41_4 (GND), U1.41_5 (GND), U1.41_6 (GND), U1.41_7 (GND), U1.41_8 (GND), U1.41_9 (GND), U1.41_10 (GND), U1.41_11 (GND), U1.41_12 (GND), U1.41_13 (GND), U1.41_14 (GND), U1.41_15 (GND), U1.41_16 (GND), U1.41_17 (GND), U1.41_18 (GND), U1.41_19 (GND), U1.41_20 (GND), U1.41_21 (GND), U2.2 (A0), U2.10 (GND), U2.19 (~OE), U3.2 (A0), U3.10 (GND), U3.19 (~OE), U4.2 (PGND), U4.10 (AGND), U4.12 (MODE), U7.29 (GND), U8.2 (S), U9.2 (S), U10.2 (GND), U11.2 (GND)
unnamed: D1.2 (A), R21.2
unnamed: D2.2 (A), R8.2
unnamed: D7.2 (A), R22.2
unnamed: D9.2 (A), R23.2
unnamed: C2.1, D5.1 (K), D6.1 (K), D15.1 (K), U11.3 (IN)
unnamed: J3.2, R35.1
unnamed: J3.4, R34.1
unnamed: J3.6, R33.1
unnamed: J3.8, R32.1
unnamed: NT1.2, R18.2
unnamed: R9.2, SW1.2 (B)
unnamed: R26.1, SW4.1 (A)
unnamed: R27.1, SW5.1 (A)
unnamed: C16.2, R17.2, R18.1, U4.4 (FB)
unnamed: C15.1, U4.5 (SS)
unnamed: C10.2, L1.1, U4.7 (SW)
unnamed: C10.1, U4.8 (VBST)
unnamed: C9.1, U4.9 (VCC)
unnamed: R8.1, U7.20 (PB9)
unnamed: R4.2, U8.3 (D)
unnamed: R16.2, U9.3 (D)

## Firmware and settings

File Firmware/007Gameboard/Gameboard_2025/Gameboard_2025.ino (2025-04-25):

//Display Refresh is on a ~ 60Hz timer interrupt. It grabs data from global variables and redraws the display if needed

//Buttons are on a pin change interrupt. They edit the values of the last time a button is pressed. 

#define REV_B01

#include <ESP32-HUB75-MatrixPanel-I2S-DMA.h>
#include "LEDMatrixConfig.h"
#include "ImageAssets.h"
#include <Adafruit_MCP23X17.h>
Adafruit_MCP23X17 mcp;

MatrixPanel_I2S_DMA *dma_display = nullptr;

int counterHigh = 0;
int counterLow = 0;
int counterThree = 0; 
int counterLowDisplay = 0;
int points = -3; 
int oldPoints = -3; 

int counterHighOld;
int counterLowOld;
int counterThreeOld; 

unsigned long delayHigh = 0;
unsigned long delayLow = 0;
unsigned long delayThree = 0; 
unsigned long delayHighOld = 0;
unsigned long delayLowOld = 0;
unsigned long delayThreeOld = 0; 

hw_timer_t * timer = NULL;

unsigned long lastButtonPressHighTime;
unsigned long lastButtonPressLowTime;
unsigned long lastButtonPressThreeTime; 

uint8_t lastButtonHigh;
uint8_t lastButtonLow;
uint8_t lastButtonThree; 

#define BlueSide

//yellow
#ifdef YellowWSide
#define colorDark 0x72a0
#define colorLight 0xfde0
#endif

//green
#ifdef GreenSide
#define colorLight 0x25a0
#define colorDark 0x1340
#endif

#ifdef RedSide
#define colorLight 0xF800
#define colorDark 0x7000
#endif

#ifdef BlueSide
#define colorLight 0x001F
#define colorDark 0x0010
#endif

void handleButtonInterrupts(uint8_t buttonNumber){
  if(buttonNumber > 2){
    if(lastButtonHigh == buttonNumber){
      lastButtonPressHighTime = millis();
      delayHigh = 0;
    }
    if(lastButtonHigh != buttonNumber && (lastButtonPressHighTime + 500) < millis()){
      counterHigh ++;
      lastButtonHigh = buttonNumber;
      lastButtonPressHighTime = millis();
      delayHigh = 0;
    }
  }

  if(buttonNumber < 3){
    if(lastButtonLow == buttonNumber){
      lastButtonPressLowTime = millis();
      delayLow = 0;
    }
    if(lastButtonLow != buttonNumber && (lastButtonPressLowTime + 500) < millis()){
      counterLow ++;
      lastButtonLow = buttonNumber;
      lastButtonPressLowTime = millis();
      delayLow = 0;
    }
  }
}

void IRAM_ATTR ButtonInterruptFunction1(){
  if(mcp.digitalRead(BUTTON_INPUT_1)){
    if(lastButtonLow == 1){
        lastButtonPressLowTime = millis();
        delayLow = 0;
      }
    if(lastButtonLow != 1 && (abs(lastButtonPressLowTime - millis()) > 1000)){
      counterLow ++;
      lastButtonLow = 1;
      lastButtonPressLowTime = millis();
      delayLow = 0;
    } 
  }
  //handleButtonInterrupts(1);
}
void IRAM_ATTR ButtonInterruptFunction2(){
  if(mcp.digitalRead(BUTTON_INPUT_2)){
    if(lastButtonLow == 2){
        lastButtonPressLowTime = millis();
        delayLow = 0;
      }
    if(lastButtonLow != 2 && (abs(lastButtonPressLowTime - millis()) > 1000)){
      counterLow ++;
      lastButtonLow = 2;
      lastButtonPressLowTime = millis();
      delayLow = 0;
    }
  }
  //handleButtonInterrupts(2);
}
void IRAM_ATTR ButtonInterruptFunction3(){
  //Serial.println("Button 3"); 
 //Serial.println(mcp.digitalRead(BUTTON_INPUT_3)); 
  if(mcp.digitalRead(BUTTON_INPUT_3)){
    if(lastButtonHigh == 3){
      lastButtonPressHighTime = millis();
      delayHigh = 0;
    }
    if(lastButtonHigh != 3 && && (abs(lastButtonPressHighTime - millis()) > 1000)){
      counterHigh ++;
      lastButtonHigh = 3;
      lastButtonPressHighTime = millis();
      delayHigh = 0;
    }
  }
  //handleButtonInterrupts(3);
}
void IRAM_ATTR ButtonInterruptFunction4(){
  //Serial.println("Button 4"); 
  //Serial.println(mcp.digitalRead(BUTTON_INPUT_4)); 
  if(mcp.digitalRead(BUTTON_INPUT_4)){
    if(lastButtonHigh == 4){
      lastButtonPressHighTime = millis();
      delayHigh = 0;
    }
    if(lastButtonHigh != 4 && (abs(lastButtonPressHighTime - millis()) > 1000)){
      counterHigh ++;
      lastButtonHigh = 4;
      lastButtonPressHighTime = millis();
      delayHigh = 0;
    }
  }
  //handleButtonInterrupts(4);
}

void IRAM_ATTR ButtonInterruptFunction5(){
  //Serial.println("Button 4"); 
  //Serial.println(mcp.digitalRead(BUTTON_INPUT_4)); 
  if(mcp.digitalRead(BUTTON_INPUT_5)){
    if(lastButtonThree == 5){
      lastButtonPressThreeTime = millis();
      delayThree = 0;
    }
    if(lastButtonThree != 5 && (abs(lastButtonPressThreeTime - millis()) > 1000)){
      counterThree ++;
      lastButtonThree = 5;
      lastButtonPressThreeTime = millis();
      delayThree = 0;
    }
  }
  //handleButtonInterrupts(4);
}

void IRAM_ATTR ButtonInterruptFunction6(){
  //Serial.println("Button 4"); 
  //Serial.println(mcp.digitalRead(BUTTON_INPUT_4)); 
  if(mcp.digitalRead(BUTTON_INPUT_6)){
    if(lastButtonThree == 6){
      lastButtonPressThreeTime = millis();
      delayThree = 0;
    }
    if(lastButtonThree != 6 && (abs(lastButtonPressThreeTime - millis()) > 1000)){
      counterThree ++;
      lastButtonThree = 6;
      lastButtonPressThreeTime = millis();
      delayThree = 0;
    }
  }
  //handleButtonInterrupts(4);
}

void drawXbm565(int x, int y, int width, int height, const char *xbm, uint16_t color = 0xffff) 
{
  if (width % 8 != 0) {
      width =  ((width / 8) + 1) * 8;
  }
    for (int i = 0; i < width * height / 8; i++ ) {
      unsigned char charColumn = pgm_read_byte(xbm + i);
      for (int j = 0; j < 8; j++) {
        int targetX = (i * 8 + j) % width + x;
        int targetY = (8 * i / (width)) + y;
        if (bitRead(charColumn, j)) {
          dma_display->drawPixel(targetX, targetY, color);
        }
      }
    }
}

void initDisplay(){
  HUB75_I2S_CFG::i2s_pins _pins={R1_PIN, G1_PIN, B1_PIN, R2_PIN, G2_PIN, B2_PIN, A_PIN, B_PIN, C_PIN, D_PIN, E_PIN, LAT_PIN, OE_PIN, CLK_PIN};
  HUB75_I2S_CFG mxconfig(PANEL_RES_X, PANEL_RES_Y, PANEL_CHAIN, _pins);
  mxconfig.clkphase = false;
  dma_display = new MatrixPanel_I2S_DMA(mxconfig);
  dma_display->setRotation(displayRotation);
  dma_display->setTextWrap(false);
  dma_display->begin();
  dma_display->setTextSize(6);  
  dma_display->setBrightness8(BRIGHTNESS); //0-255
}

void buttonSetup(){
  /*pinMode(BUTTON_INPUT_1, INPUT_PULLUP);
  pinMode(BUTTON_INPUT_2, INPUT_PULLUP);
  pinMode(BUTTON_INPUT_3, INPUT_PULLUP);
  pinMode(BUTTON_INPUT_4, INPUT_PULLUP);*/ 

  if (!mcp.begin_I2C()) {
  //if (!mcp.begin_SPI(CS_PIN)) {
    Serial.println("Error.");
    while (1);
  }

  // configure pin for input with pull up
  mcp.pinMode(BUTTON_INPUT_1, INPUT_PULLUP);
  mcp.pinMode(BUTTON_INPUT_2, INPUT_PULLUP);
  mcp.pinMode(BUTTON_INPUT_3, INPUT_PULLUP);
  mcp.pinMode(BUTTON_INPUT_4, INPUT_PULLUP);
  mcp.pinMode(BUTTON_INPUT_5, INPUT_PULLUP);
  mcp.pinMode(BUTTON_INPUT_6, INPUT_PULLUP);

  int b1 = mcp.digitalRead(BUTTON_INPUT_1); 
  int b2 = mcp.digitalRead(BUTTON_INPUT_2); 
  int b3 = mcp.digitalRead(BUTTON_INPUT_3); 
  int b4 = mcp.digitalRead(BUTTON_INPUT_4); 
  int b5 = mcp.digitalRead(BUTTON_INPUT_5); 
  int b6 = mcp.digitalRead(BUTTON_INPUT_6); 


  while(b1|b2|b3|b4|b5|b6){

    int even = 0; 
    int odd = 0; 
    int sum = 0; 

    if(b1){
      sum++; 
      odd = 1; 
    }
    if(b2){
      sum++;
      even = 1; 
    }
    if(b3){
      sum++; 
      odd = 1; 
    }
    if(b4){
      sum++;
      even = 1; 
    }
    if(b5){
      sum++; 
      odd = 1; 
    }
    if(b6){
      sum++;
      even = 1; 
    }
    
    Serial.println(sum);
    if(sum != 3){
      dma_display->setBrightness8(100); //0-255
      drawXbm565(16,0,32,32, SwitchDisconnectedRed, dma_display->color565(255,0,0));
      drawXbm565(16,0,32,32, SwitchDisconnectedGrey, dma_display->color565(128,128,128));
      drawXbm565(16,0,32,32, SwitchDisconnectedWhite, dma_display->color565(128,128,128));
      dma_display->setTextColor(dma_display->color444(255, 0, 0));
      dma_display->setTextSize(1);
      dma_display->setCursor(27,9);

      if(even){
        dma_display->println("0");
      }
      else if(odd){
        dma_display->println("1");
      }

    } else {
      break;
    }

    
    delay(100);
  }

  dma_display->setBrightness8(BRIGHTNESS); //0-255
  attachInterrupt(digitalPinToInterrupt(BUTTON_INPUT_1), ButtonInterruptFunction1, RISING);
  attachInterrupt(digitalPinToInterrupt(BUTTON_INPUT_2), ButtonInterruptFunction2, RISING);
  attachInterrupt(digitalPinToInterrupt(BUTTON_INPUT_3), ButtonInterruptFunction3, RISING);
  attachInterrupt(digitalPinToInterrupt(BUTTON_INPUT_4), ButtonInterruptFunction4, RISING);
  attachInterrupt(digitalPinToInterrupt(BUTTON_INPUT_5), ButtonInterruptFunction5, RISING);
  attachInterrupt(digitalPinToInterrupt(BUTTON_INPUT_6), ButtonInterruptFunction6, RISING);

}

void IRAM_ATTR timerISR() {
  if(!((counterHigh == counterHighOld) && (counterLow == counterLowOld) && ((delayHigh == delayHighOld) || delayHigh > 32) && ((delayLow == delayLowOld) || delayLow > 32)))
  {
    dma_display->clearScreen();
    dma_display->setTextSize(2);
    updatePointsDisplay();
    //updateDelayBarsDisplay();

    //horizontal bars 
    dma_display->writeFillRect(0, 0, 64, 5, colorLight);
    dma_display->writeFillRect(0, 27, 64, 5, colorLight);

    //vertical bars 
    dma_display->writeFillRect(0, 0, 5, 32, colorLight);
    dma_display->writeFillRect(59, 0, 5, 32, colorLight);

    counterHighOld = counterHigh;
    counterLowOld = counterLow;
    counterThreeOld = counterThree; 
    delayHighOld = delayHigh;
    delayLowOld = delayLow;
    delayThreeOld = delayThree; 
  }
  delayHigh++;
  delayLow++;
  delayThree++;


}

void timerISRInit(){
  timer = timerBegin(60000); // 60 kHz timer
  timerAttachInterrupt(timer, &timerISR); // Attach ISR
  timerAlarm(timer, 1000, true, 0); //calls interrupt every 60kHz/1000 = 60 Hz
}

void updatePointsDisplay(){
  //horizontal bars 
  dma_display->writeFillRect(0, 0, 64, 5, colorLight);
  dma_display->writeFillRect(0, 27, 64, 5, colorLight);

  //vertical bars 
  dma_display->writeFillRect(0, 0, 5, 32, colorLight);
  dma_display->writeFillRect(59, 0, 5, 32, colorLight);

  if(points >= 100){
    int hundreds = (points - (points % 100))/100;
    int tens = ((points - hundreds * 100) - (points % 10))/10;
    int ones = points % 10;
    // Serial.print("High Hundreds: ");
    // Serial.print(hundreds);
    // Serial.print(", tens: ");
    // Serial.print(tens);
    // Serial.print(", ones: ");
    // Serial.println(ones);
    dma_display->setTextColor(0xFFFF, 0x0);
    dma_display->setCursor(15, 9);
    dma_display->print(hundreds);
    dma_display->setCursor(27, 9);
    dma_display->print(tens);
    dma_display->setCursor(39, 9);
    dma_display->print(ones);
    }
    else if(points >= 10){
      dma_display->setCursor(21, 9);
      dma_display->println(points);
    }
    else{
      dma_display->setCursor(27, 9); // x originally 11
      dma_display->println(points);
    }
/*
    counterLowDisplay = counterLow / 2;
    if(counterLowDisplay >= 100){
      int hundreds = (counterLowDisplay - (counterLowDisplay % 100))/100;
      int ones = counterLowDisplay % 10;
      int tens = ((counterLowDisplay - (hundreds * 100)) - ones)/10;
      
      // Serial.print("Low Hundreds: ");
      // Serial.print(hundreds);
      // Serial.print(", tens: ");
      // Serial.print(tens);
      // Serial.print(", ones: ");
      // Serial.println(ones);
      dma_display->setCursor(0, 37);
      dma_display->print(hundreds);
      dma_display->setCursor(11, 37);
      dma_display->print(tens);
      dma_display->setCursor(22, 37);
      dma_display->print(ones);
    }
    else if(counterLowDisplay >= 10){
      dma_display->setCursor(5, 37);
      dma_display->println(counterLowDisplay);
    }
    else{
      dma_display->setCursor(11, 37);
      dma_display->println(counterLowDisplay);
    }
    if(counterLow % 2){
      dma_display->setCursor(21, 52);
      dma_display->setTextSize(1);
      dma_display->print(".5");
      dma_display->setTextSize(2);
    }*/
}

void updateDelayBarsDisplay(){
  if(delayHigh >= 32){
    dma_display->writeFillRect(0, 0, 64, 5, colorLight);
    dma_display->writeFillRect(0, 27, 64, 5, colorLight);
  }
  else if(delayHigh > 0){
    dma_display->writeFillRect(0, 0, delayHigh, 5, colorDark);
  }

  if(delayLow >= 32){
    dma_display->writeFillRect(0, 59, 32, 5, colorLight);
  }
  else if(delayLow > 0){
    dma_display->writeFillRect(0, 59, delayLow, 5, colorDark);
  }
}

void setup() {
  Serial.begin(115200);
  
  initDisplay();
  buttonSetup();
  timerISRInit();

  //bars 
  //dma_display->writeFillRect(0, 0, 64, 5, colorLight);
  // dma_display->writeFillRect(0, 27, 64, 5, colorLight);
}

void loop() {
  /*
  Serial.print("Counter High: ");
  Serial.print(counterHigh);
  Serial.print(", Counter Low: ");
  Serial.print(counterLow);
  Serial.print(", Counter Three: ");
  Serial.print(counterThree);
*/

  points = counterLow+counterHigh+counterThree-3; 

  //Serial.print(", points: ");
  //Serial.println(points);

  ButtonInterruptFunction1(); 
  ButtonInterruptFunction2(); 
  ButtonInterruptFunction3(); 
  ButtonInterruptFunction4(); 
  ButtonInterruptFunction5();
  ButtonInterruptFunction6();

  if(points!=oldPoints){
    dma_display->clearScreen();
    // updateDelayBarsDisplay(); 
    updatePointsDisplay();
    oldPoints = points; 
  }

  

  //delay(200);
}

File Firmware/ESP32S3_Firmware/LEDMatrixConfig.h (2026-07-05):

#ifndef LEDMatrixConfig_h
#define LEDMatrixConfig_h

#ifdef REV_A02

#define R1_PIN 42
#define G1_PIN 41
#define B1_PIN 40
#define R2_PIN 38
#define G2_PIN 39
#define B2_PIN 37
#define A_PIN 48
#define B_PIN 36
#define C_PIN 12
#define D_PIN 45
#define E_PIN 14
#define LAT_PIN 21
#define OE_PIN 13
#define CLK_PIN 47

#endif

#ifdef REV_B01

#define R1_PIN 41
#define G1_PIN 40
#define B1_PIN 39
#define R2_PIN 37
#define G2_PIN 38
#define B2_PIN 36
#define A_PIN 47
#define B_PIN 35
#define C_PIN 45
#define D_PIN 48
#define E_PIN 13
#define LAT_PIN 14
#define OE_PIN 12
#define CLK_PIN 21

#define NEOPIXEL_POWER 3
#define NEOPIXEL_DATA 46
#define ALS_PIN 1
#define TOP_BUTTON 10
#define BOTTOM_BUTTON 11
#define BUTTON_INPUT_1 2
#define BUTTON_INPUT_2 43
#define BUTTON_INPUT_3 44
#define BUTTON_INPUT_4 42

#define flashlightLeft 15
#define flashlightRight 16

#endif

#define PANEL_RES_X 64      // Number of pixels wide of each INDIVIDUAL panel module. 
#define PANEL_RES_Y 32     // Number of pixels tall of each INDIVIDUAL panel module.
#define PANEL_CHAIN 1      // Total number of panels chained one to another

#define displayRotation 0

#endif

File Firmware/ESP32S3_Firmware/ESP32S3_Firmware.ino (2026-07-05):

#define REV_B01

#include <ESP32-HUB75-MatrixPanel-I2S-DMA.h>
#include "LEDMatrixConfig.h"
#include "MBTA_API_Config.h"
#include <WiFi.h>
#include <HTTPClient.h>
#include <ArduinoJson.h>
#include <NTPClient.h>
#include <string.h>
#include "logos.h"
#include "WifiPassword.h" //defines const char *password = "password here";

#define BRIGHTNESS 60


String DisplayBuffer[8];
uint8_t LineColorsRed[8];
uint8_t LineColorsGreen[8];
uint8_t LineColorsBlue[8];

uint8_t DefaultTextColor[3] = {186, 85, 211};
uint8_t MBTAColor[3] = {255,255,0};
int MBTAArrivalTimes[100];
uint8_t MITColor[3] = {255,0,44};

const char *ntpServer = "pool.ntp.org";
const long gmtOffset_sec = -4 * 60 * 60; // Your GMT offset in seconds
const int daylightOffset_sec = 3600; // Daylight offset in seconds (1 hour)
WiFiUDP ntpUDP;
NTPClient timeClient(ntpUDP, ntpServer, gmtOffset_sec, daylightOffset_sec);

MatrixPanel_I2S_DMA *dma_display = nullptr;

hw_timer_t * timer = NULL;

HTTPClient httpMBTA;

void drawXbm565(int x, int y, int width, int height, const char *xbm, uint16_t color = 0xffff) 
{
  if (width % 8 != 0) {
      width =  ((width / 8) + 1) * 8;
  }
    for (int i = 0; i < width * height / 8; i++ ) {
      unsigned char charColumn = pgm_read_byte(xbm + i);
      for (int j = 0; j < 8; j++) {
        int targetX = (i * 8 + j) % width + x;
        int targetY = (8 * i / (width)) + y;
        if (bitRead(charColumn, j)) {
          dma_display->drawPixel(targetX, targetY, color);
        }
      }
    }
}

void IRAM_ATTR timerISR() {
  //Serial.println("Updating the display with interrupts! Here's the display stuffs"); // Print to serial
  refreshScreen();
  drawXbm565(57, 8, 7, 7, MBTA_bits, dma_display->color565(MBTAColor[0],MBTAColor[1],MBTAColor[2]));
  drawXbm565(57, 16, 7, 7, MBTA_bits, dma_display->color565(MBTAColor[0],MBTAColor[1],MBTAColor[2]));
  drawXbm565(57, 24, 7, 7, MBTA_bits, dma_display->color565(MBTAColor[0],MBTAColor[1],MBTAColor[2]));
  //drawXbm565(40, 0, 6, 7, bus_bits, dma_display->color565(MBTAColor[0],MBTAColor[1],MBTAColor[2]));
  drawXbm565(0, 56, 7, 7, clock_circle_bits, dma_display->color565(MBTAColor[0],MBTAColor[1],MBTAColor[2]));
  drawXbm565(0, 56, 7, 7, clock_hands_bits, dma_display->color565(MITColor[0],MITColor[1],MITColor[2]));

}

void refreshScreen(){
  dma_display->clearScreen();
  dma_display->setCursor(0, 0);    // start at top left, with 8 pixel of spacing
  for(int i = 0; i < 8; i++){
    if(i == 7){
      dma_display->setCursor(5, 56);
    }
    int redraw = 0;
    if(i == 4){
      String text = DisplayBuffer[i];
      if(text[7] == 'i'){
        drawText(DisplayBuffer[i].substring(0,5), LineColorsRed[i],LineColorsGreen[i],LineColorsBlue[i]);
        dma_display->setCursor(33, 32);
        drawText("min", LineColorsRed[i],LineColorsGreen[i],LineColorsBlue[i]);
        redraw = 1;
      }
    }
    if(i == 5){
      String text = DisplayBuffer[i];
      if(text[7] == 'i'){
        drawText(DisplayBuffer[i].substring(0,5), LineColorsRed[i],LineColorsGreen[i],LineColorsBlue[i]);
        dma_display->setCursor(33, 40);
        drawText("min", LineColorsRed[i],LineColorsGreen[i],LineColorsBlue[i]);
        redraw = 1;
      }
    }
    if(!redraw){
      drawText(DisplayBuffer[i], LineColorsRed[i],LineColorsGreen[i],LineColorsBlue[i]);
    }
  }
}

void timerISRInit() {
  timer = timerBegin(1000000);           // 1 MHz timer tick = 1 us
  timerAttachInterrupt(timer, &timerISR);
  timerAlarm(timer, 1000000, true, 0);   // 1s period, autoreload, unlimited reloads
}

void drawText(String text, uint8_t r, uint8_t g, uint8_t b)
{
  dma_display->setTextSize(1);     // size 1 == 8 pixels high
  dma_display->setTextWrap(false); // Don't wrap at end of line - will do ourselves
  dma_display->setTextColor(dma_display->color565(r,g,b));
  dma_display->println(text);
}

void initMatrix(){

  DisplayBuffer[0] = "66 Harvard";
  DisplayBuffer[1] = "";
  DisplayBuffer[2] = "";
  DisplayBuffer[3] = "";
  DisplayBuffer[4] = "";
  DisplayBuffer[5] = "";
  DisplayBuffer[6] = "";
  DisplayBuffer[7] = "";
  for (int i = 0; i < 8; i++) {
    LineColorsRed[i] = DefaultTextColor[0];
    LineColorsGreen[i] = DefaultTextColor[1];
    LineColorsBlue[i] = DefaultTextColor[2];
  }

  HUB75_I2S_CFG::i2s_pins _pins={R1_PIN, G1_PIN, B1_PIN, R2_PIN, G2_PIN, B2_PIN, A_PIN, B_PIN, C_PIN, D_PIN, E_PIN, LAT_PIN, OE_PIN, CLK_PIN};
  HUB75_I2S_CFG mxconfig(PANEL_RES_X, PANEL_RES_Y, PANEL_CHAIN, _pins);
  //mxconfig.gpio.e = E_PIN;
  mxconfig.clkphase = false;
  dma_display = new MatrixPanel_I2S_DMA(mxconfig);
  dma_display->setRotation(displayRotation);
  dma_display->begin();
  dma_display->setBrightness8(BRIGHTNESS); //0-255
  dma_display->clearScreen();
}

void initWifi(){
  WiFi.begin(ssid, password);
  while (WiFi.status() != WL_CONNECTED) {
    delay(1000);
    Serial.println("Connecting to WiFi...");
    dma_display->clearScreen();
    drawText("Connecting", 255,0,0);
  }
  Serial.println("Connected to WiFi");
  drawText("Connected", 0,255,0);
  delay(1000);
  httpMBTA.begin(apiEndpointMBTA);
}

struct MBTAPredictionCandidate {
  int minutesAway;
  String displayText;
};

int getPredictionMinutesAway(String eventTime) {
  if (eventTime.length() < 16) {
    return -1;
  }

  int eventMinutes = eventTime.substring(11, 13).toInt() * 60 + eventTime.substring(14, 16).toInt();
  int nowMinutes = timeClient.getHours() * 60 + timeClient.getMinutes();
  int minutesAway = eventMinutes - nowMinutes;

  // Handle predictions after midnight while current time is before midnight.
  if (minutesAway < -12 * 60) {
    minutesAway += 24 * 60;
  }

  // Drop stale predictions from earlier today. Keep buses that are arriving now.
  if (minutesAway < -1) {
    return -1;
  }
  if (minutesAway < 0) {
    minutesAway = 0;
  }

  return minutesAway;
}

void sortPredictionsByArrival(int *minutesAway, String *displayText, int count) {
  for (int i = 0; i < count - 1; i++) {
    for (int j = i + 1; j < count; j++) {
      if (minutesAway[j] < minutesAway[i]) {
        int tmpMinutes = minutesAway[i];
        minutesAway[i] = minutesAway[j];
        minutesAway[j] = tmpMinutes;

        String tmpText = displayText[i];
        displayText[i] = displayText[j];
        displayText[j] = tmpText;
      }
    }
  }
}
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

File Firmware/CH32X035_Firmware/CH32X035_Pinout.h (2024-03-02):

#ifdef REV_A01

#define PD_EN PA2
#define PD_SENSE PA3
#define BARREL_EN PA0
#define BARREL_SENSE PA1
#define BUCK_EN PB3
#define LED_BUILTIN PB12

#endif

#ifdef REV_A02

#define PD_EN PA2
#define PD_SENSE PA5
#define BARREL_EN PA0
#define BARREL_SENSE PA1
#define BUCK_EN PB3
#define LED_BUILTIN PB12

#endif

#ifdef REV_B01

#define PD_EN PA2
#define PD_SENSE PA5
#define BARREL_EN PA0
#define BARREL_SENSE PA1
#define BUCK_EN PB3
#define LED_BUILTIN PB9

#endif

#ifdef REV_B02

  #define PD_EN PA2
  #define PD_SENSE PA5
  #define BARREL_EN PA0
  #define BARREL_SENSE PA1
  #define BUCK_EN PB3
  #define LED_BUILTIN PB9
  #define SenseDividerRatio 10

#endif

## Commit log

2024-01-28 laid out
    [ESP32-S3-HUB75-Driver.kicad_pcb, ESP32-S3-HUB75-Driver.kicad_sch, PowerMux.kicad_sch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]
2024-02-03 updated schematic to look neater
    [ESP32-S3-HUB75-Driver.kicad_pcb, ESP32-S3-HUB75-Driver.kicad_sch, PowerMux.kicad_sch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]
2024-02-03 restructured folders
    [ESP32-S3-HUB75-Driver.kicad_pcb, ESP32-S3-HUB75-Driver.kicad_sch, PowerMux.kicad_sch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]
2024-02-07 added B01
    [ESP32-S3-HUB75-Driver.kicad_pcb, ESP32-S3-HUB75-Driver.kicad_sch, JST_VH_S4P-VH_1x04_P3.96mm_Horizontal.STEP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]
2024-02-07 added LED test for CH32X035 fw
2024-02-07 Test for doing timer interrupts on ESP32 S3
2024-02-14 B02: edited passive values
    HSS slew rate edited by replacing slew-rate limiting capacitor to 4.7uF/35V
    24V LED resistor changed to 10K to not burn an LED
    Resistor divider for voltage sense edited to 18K/3,3K
    [ESP32-S3-HUB75-Driver.kicad_sch, PowerMux.kicad_sch, TPS51385.kicad_sch]
2024-02-14 added revision-based pin definitions
2024-03-02 Added automatic power input switching
2024-03-02 Added divider ratio for sense circuit by hardware revisions
2024-03-02 added button support
2024-03-18 Added graphic for disconnected switches
2024-03-18 Added graphics on buttons display
2024-03-20 Started Auxillary Board
    [BoardOutline.dxf, Hub75-Driver-Auxillary-Board.kicad_pcb, Hub75-Driver-Auxillary-Board.kicad_sch]
2024-04-02 added detection for switches not connected
2025-03-06 idk man seems like old code I didn't commit
    [Gameboard_Spaceship.ino, LEDMatrixConfig.h]
2025-03-18 timer updated for 3.0.x ESP32 API support
2025-04-01 Button Template Code
    Trial Code Seprate from the Gameboard code for the buttons
2025-04-03 4/2 Work
    - horizontal letters
    - trying to get button interrupt to work
2026-07-04 update timerISR to new API
